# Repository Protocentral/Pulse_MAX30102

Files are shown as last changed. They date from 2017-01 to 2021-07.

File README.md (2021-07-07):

Pulse
================================

[Don't have it yet? Buy one here: Pulse+ Pulse-Ox & Heart Rate Sensor based on MAX30102 (PC-MED-0402)](https://protocentral.com/product/pulse-3-pulse-ox-heart-rate-sensor-based-on-max30102-qwiic-compatible/)
Pulse+ Pulse-Ox & Heart Rate Sensor

This is the new Pulse Plus building on our earlier Pulse board by adding the new MAX30102 chip from Maxim that provides better performance.

The Pulse sensor board from ProtoCentral is our new addition to our open medical hardware line-up. Maxim's MAX30100 is a great new product that combines everything required for a pulse oximeter (including the LEDs and Photodiode !!) on a single tiny chip.

Measuring 14 mm wide and 40 mm long, this board is easily wearable on the finger to measure the pulse of blood. We even provide a Velcro strap to hold it.
Important Note: This device is only meant to be used for Research purposes and is NOT to be used as a medical device. This product is not FDA, CE or FCC approved for consumer use. 

Features:
* Integrates a complete pulse oximeter including the optics. No need for a separate probe. 
* Easy-to-use I2C interface to connect to any host microcontroller
* 880 nm Infrared and 660 nm Red LEDs
* Arduino library available
* Calculates Spo2 values with provided code
* Real-time display of PPG (Photoplethysmogram)

Includes:
----------
* 1x ProtoCentral Pulse Oximeter breakout
* 1x Welgro strap

Repository Contents
-------------------
* **/Software** - Arduino and Processing library and example sketches.
* **/Hardware** - All Eagle design files (.brd, .sch)
* **/extras** -   includes the datasheet

Wiring the Breakout to your Arduino
------------------------------------
Connection with the Arduino board is as follows:
 
|Pulse pin label | Arduino Connection |Pin Function |
|--- |:---:|---:|
| VCC | +5V |  Supply voltage  | 
| SCL | A5 |  Serial clock |
| SDA | A4 |  Serial data |
| GND | |  Gnd |

Using Processing - Data Visualization Software (New!)
-----------------------------------------------------
 Processing is a data visualization software, in existence since 2001, used by artists and scientists alike. It’s an open source coding framework based on Java. If you are familiar with the Arduino environment, the Processing IDE is similar and you won’t have much of a learning curve to climb!
 
 The following are the steps to run the code:

### 1. Download Processing for your operating system

 Download the processing ide latest version from the link

* [MAC] (http://download.processing.org/processing-3.2.1-macosx.zip)
* [Linux 32-bit] (http://download.processing.org/processing-3.2.1-linux32.tgz)
* [Linux 64-bit] (http://download.processing.org/processing-3.2.1-linux64.tgz)
* [Windows 32-bit] (http://download.processing.org/processing-3.2.1-windows32.zip)
* [Windows 64-bit] (http://download.processing.org/processing-3.2.1-windows64.zip)

 Once downloaded, unzip the archive and install the app as per your OS.

### 2. Download the Processing code for Pulse Oximeter visualization

 a. Download the necessary files & directories or clone to your desktop from GitHub.

 b. Unzipping the archive should make a folder by name Pulse that contains the visualization code.

 c. Locate the Processing sketchbook directory on your computer. This should have been created automatically when you installed processing. Depending on your operating system, the path will be as follows:

* On Windows: c:/My Documents/Processing/
* On MAC: /Users/your_user_name/Documents/Processing/
* On Linux: /Home/your_user_name/sketchbook/

**Note:** This directory appears as "Processing" on Windows/Mac, and goes by the name "Sketchbook" on Linux. Create a subdirectory by name "libraries" if one doesn't exist already.

 d. From the above mentioned "Pulse" directory Copy/Move the contents of the Pulse-master/Software/Processing/openview_oximeter folder to the Processing sketchbook directory which is also mentioned above (Locate the Processing sketchbook)

 e. Finally, copy the G4P directories from Pulse-master\Processing\libraries and paste them into the libraries directory of your Processing sketchbook.

 f. You are all set now to get your first PPG wave form and SpO2 reading visualized from the Pulse!

### 3. Open Processing & launch the openview_oximeter

 a. If Processing IDE was open, close it and reopen to refresh the libraries and sketches. The repositories are not refreshed if the IDE was open while the Sketches and Libraries were being updated.

 b. Double-click any of the .pde files in the openview_oximeter directory to open all of the pulse oximeter code in the Processing IDE.

 c. If everything done so far was good, clicking the "run" button on the top left corner of the IDE, should run the code! If it does not, make sure you installed your libraries correctly.

 d. Once the GUI is running, select the port connect with pulse oximeter shield from the "SELECT PORT" dropdown as shown in the figure below

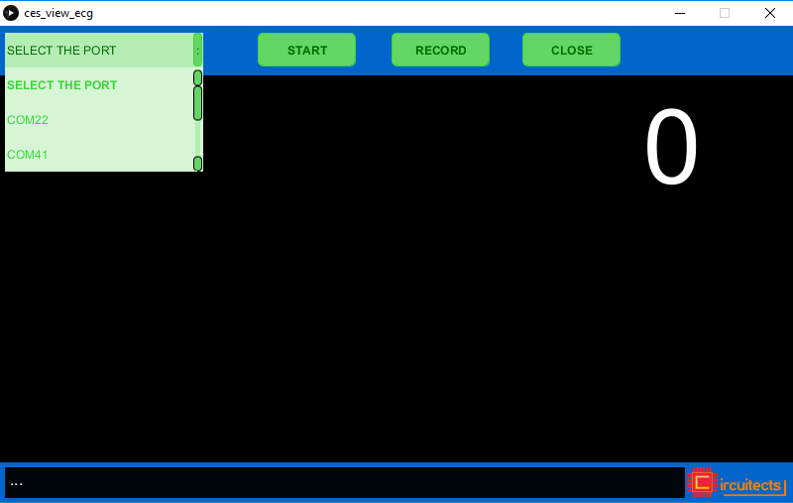
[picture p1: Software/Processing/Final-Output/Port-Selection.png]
Port Selection


 e. Once the port selection is appropriate the START button gets enabled. Click "START" to initiate visualization

 f. You should see the PPG ( RED and IR) waves generated with the values obtained from the Pulse as shown below.

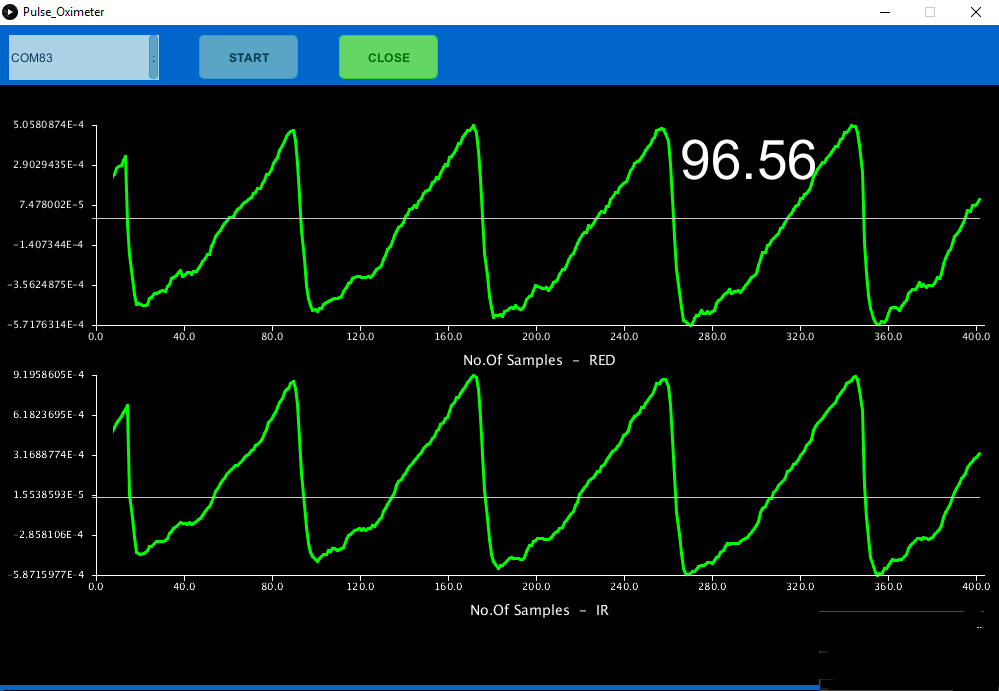
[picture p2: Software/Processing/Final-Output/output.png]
PPG Wave Form in Processing


License Information
===================

This product is open source! Both, our hardware and software are open source and licensed under the following licenses:

Hardware
---------

**All hardware is released under [Creative Commons Share-alike 4.0 International](http://creativecommons.org/licenses/by-sa/4.0/).**


You are free to:

* Share — copy and redistribute the material in any medium or format
* Adapt — remix, transform, and build upon the material for any purpose, even commercially.
The licensor cannot revoke these freedoms as long as you follow the license terms.

Under the following terms:

* Attribution — You must give appropriate credit, provide a link to the license, and indicate if changes were made. You may do so in any reasonable manner, but not in any way that suggests the licensor endorses you or your use.
* ShareAlike — If you remix, transform, or build upon the material, you must distribute your contributions under the same license as the original.

Software
--------

**All software is released under the MIT License(http://opensource.org/licenses/MIT).**

THE SOFTWARE IS PROVIDED "AS IS", WITHOUT WARRANTY OF ANY KIND, EXPRESS OR IMPLIED, INCLUDING BUT NOT LIMITED TO THE WARRANTIES OF MERCHANTABILITY, FITNESS FOR A PARTICULAR PURPOSE AND NONINFRINGEMENT. IN NO EVENT SHALL THE AUTHORS OR COPYRIGHT HOLDERS BE LIABLE FOR ANY CLAIM, DAMAGES OR OTHER LIABILITY, WHETHER IN AN ACTION OF CONTRACT, TORT OR OTHERWISE, ARISING FROM, OUT OF OR IN CONNECTION WITH THE SOFTWARE OR THE USE OR OTHER DEALINGS IN THE SOFTWARE.

Please check [*LICENSE.md*](LICENSE.md) for detailed license descriptions.

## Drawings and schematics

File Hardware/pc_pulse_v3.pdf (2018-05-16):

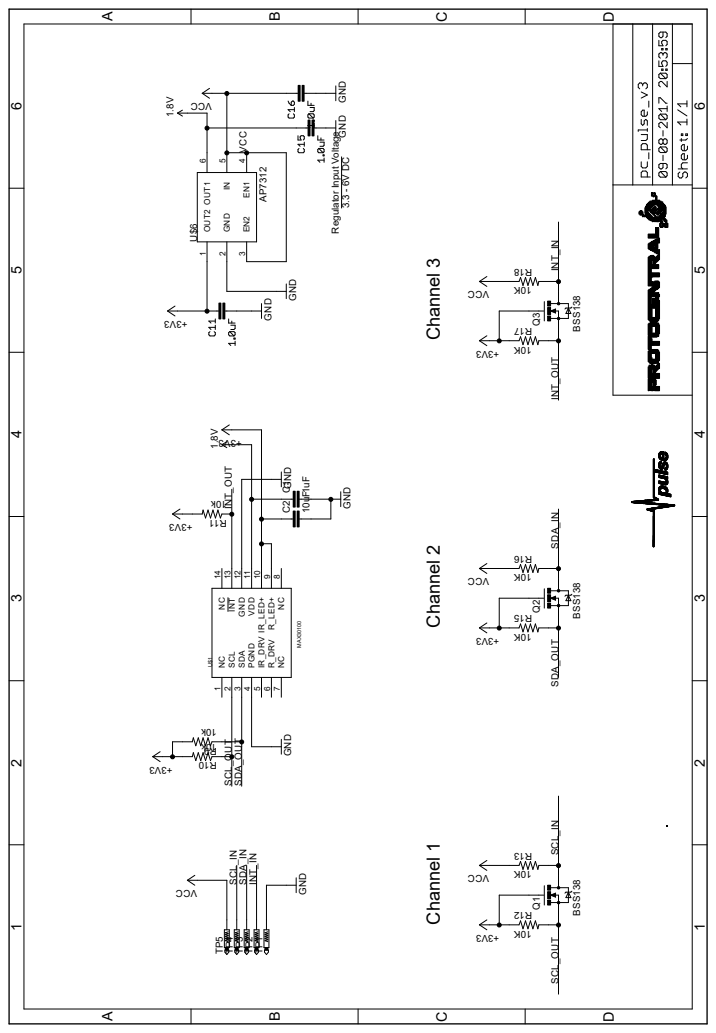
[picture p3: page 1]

R18 TP5 TP4 TP3 TP2 TP1 OUT2 1 GND 2 EN2 3 EN1 4 IN 5 OUT1 6 U$6 SCL_OUT SCL_OUT SDA_OUT SDA_OUT INT_OUT INT_OUT VCC SCL_INSCL_IN SDA_IN SDA_IN INT_IN INT_IN ABCD 1 2 3 4 5 6 ABCD 1 2 3 4 5 6

VCC AP7312 GND GND GND GND 1.8V

VCC Channel 1 Channel 2 Channel 3 NC 1 SCL 2 SDA 3 PGND 4 IR_DRV 5 R_DRV 6 NC 7 NC 8 R_LED+ 9 IR_LED+ 10 VDD 11 GND 12 INT 13 NC 14 U$1 C1 C2

Regulator Input Voltage 3.3 - 6V DC MAX30100 1uF 10uF GNDGND GND GND VCC

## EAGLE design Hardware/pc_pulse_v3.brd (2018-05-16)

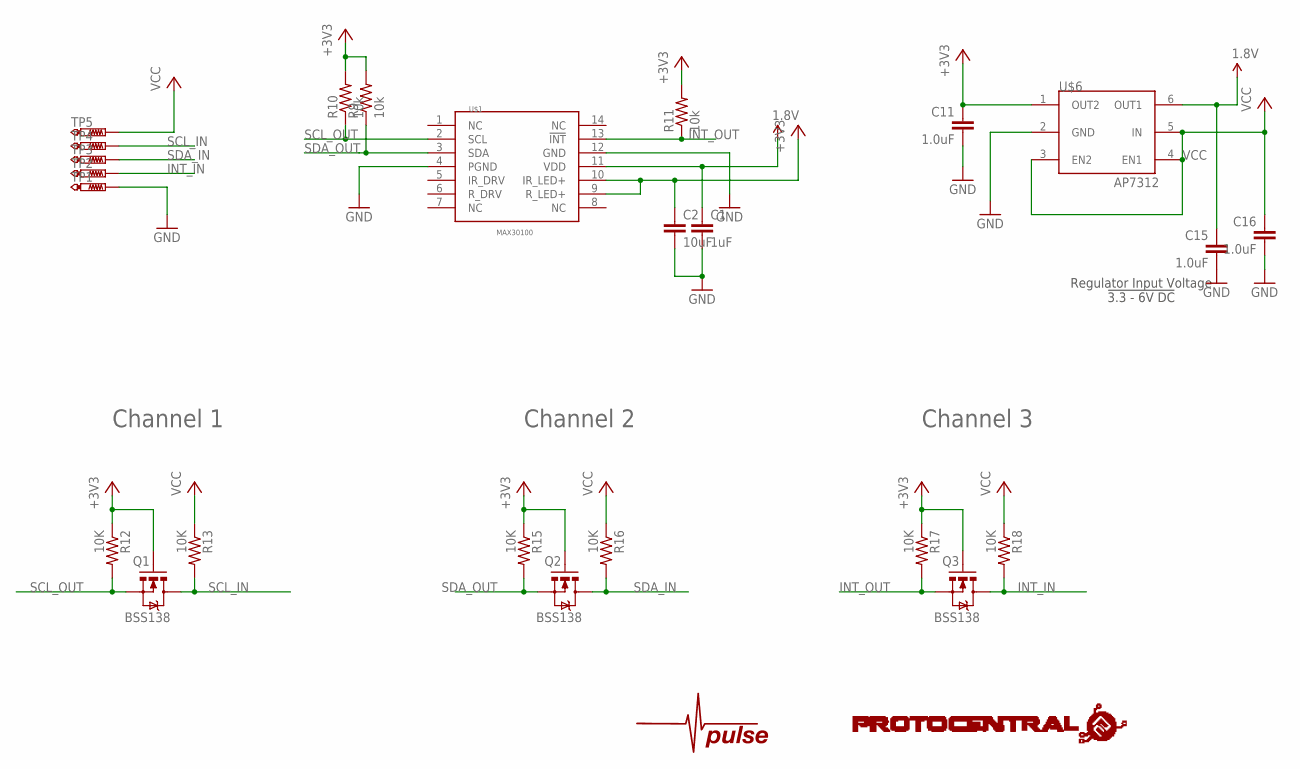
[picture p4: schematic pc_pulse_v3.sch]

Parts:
C1: 1uF; C0805
C2: 10uF; C0805
C11, C15, C16: 1.0uF; 0805
Q1, Q2, Q3: BSS138; SOT23-3
R9, R10, R11: 10k; R0402
R12, R13, R15, R16, R17, R18: 10K; 0402-RES
TP1, TP2, TP3, TP4, TP5: PTR1TP20SQ; TP20SQ
U$1: MAX30100; OESIP-14
U$3: PROTY-LOGO; LOGO-PROTY
U$4: PULSE
U$6: AP7312; SOT26
U$7: PROTY_LOGO_WITH_TEXT; PROTY_WITH_TEXT

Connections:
1.8V: C1.1, C15.1, U$1.11 (VDD), U$6.6 (OUT1)
+3V3: C2.1, C11.1, Q1.1 (G), Q2.1 (G), Q3.1 (G), R9.2, R10.2, R11.2, R12.1, R15.1, R17.1, U$1.9 (R_LED+), U$1.10 (IR_LED+), U$6.1 (OUT2)
GND: C1.2, C2.2, C11.2, C15.2, C16.2, TP1.TP, U$1.4 (PGND), U$1.12 (GND), U$6.2 (GND)
INT_IN: Q3.3 (D), R18.2, TP2.TP
INT_OUT: Q3.2 (S), R11.1, R17.2, U$1.13 (!INT)
SCL_IN: Q1.3 (D), R13.2, TP4.TP
SCL_OUT: Q1.2 (S), R10.1, R12.2, U$1.2 (SCL)
SDA_IN: Q2.3 (D), R16.2, TP3.TP
SDA_OUT: Q2.2 (S), R9.1, R15.2, U$1.3 (SDA)
VCC: C16.1, R13.1, R16.1, R18.1, TP5.TP, U$6.3 (EN2), U$6.4 (EN1), U$6.5 (IN)

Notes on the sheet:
Channel 1
Channel 2
Channel 3
Regulator Input Voltage !3.3 - 6V DC!

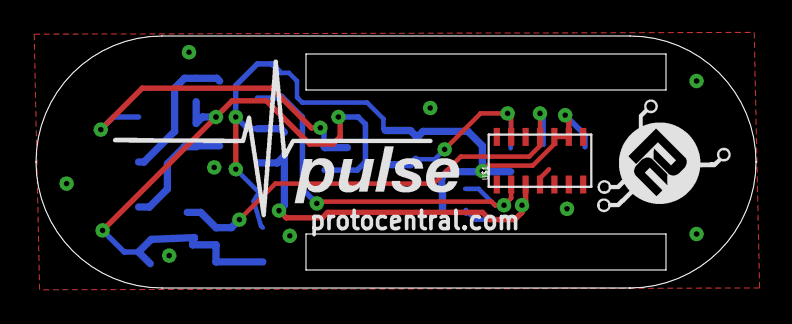
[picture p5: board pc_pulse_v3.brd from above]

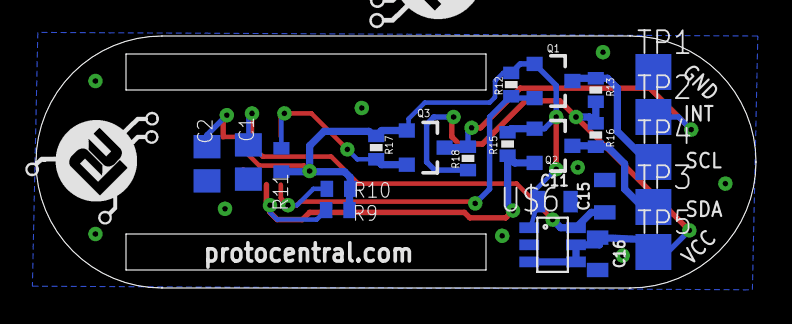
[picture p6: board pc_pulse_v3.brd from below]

Board: 4 copper layers, 40.0 x 14.0 mm, 28 parts (25 on the bottom side), 10 nets.

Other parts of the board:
U$5: PROTY-LOGO; LOGO-PROTY

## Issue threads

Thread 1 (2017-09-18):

error in the Max30102

omsrivathsa, 2017-09-18:
i have been trying to execute Max30102 break out board   from protocentral  is heck of mess !!! unable to decode the break out

VenkateshBhat, 2017-09-18:
@omsrivathsa
Sorry for the inconvenience caused, could you please attach the error message you are getting.

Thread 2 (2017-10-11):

issue with reading of data

SayedBaqer, 2017-10-11:
hi,
thanks for your hard work on this library,
i have GY-max30102 i try your library and sketch,
but output is not possible to understand only squares!
i need to use it for test pulse of human then if it work i need to use it for egg pulse monitor if you can help

VenkateshBhat, 2017-10-11:
@SayedBaqer thanks for your kind words!,
Could you please share the output graph?

SayedBaqer, 2017-10-11:
I display by Serial monitors,
If there is any way to get only the pulse rate in Pulse per minute will be great, and later if we can adjust it to be able to ready egg embryo pulse

On Oct 11, 2017, at 16:44, Venkatesh Bhat <notifications@github.com<mailto:notifications@github.com>> wrote:

@SayedBaqer<https://github.com/sayedbaqer> thanks for your kind words!,
Could you please share the output graph?

—
You are receiving this because you were mentioned.
Reply to this email directly, view it on GitHub<https://github.com/Protocentral/Pulse_MAX30102/issues/2#issuecomment-335814151>, or mute the thread<https://github.com/notifications/unsubscribe-auth/ANY6VbJGcDfN7lsfdS_mlQS57SZz0mRKks5srMYogaJpZM4P1dnP>.

VenkateshBhat, 2017-10-12:
The sample code we provided plots the reflected RED and IR light. Sparkfun has a library for SpO2 calculation check here -https://github.com/sparkfun/SparkFun_MAX3010x_Sensor_Library

SayedBaqer, 2017-10-12:
Dose not work well on GY-MAX-30102

Best regards,
Sayed Baqer Mohammed Alseba

On Oct 12, 2017, at 08:19, Venkatesh Bhat <notifications@github.com<mailto:notifications@github.com>> wrote:

The sample code we provided plots the reflected RED and IR light. Sparkfun has a library for SpO2 calculation check here -https://github.com/sparkfun/SparkFun_MAX3010x_Sensor_Library

—
You are receiving this because you were mentioned.
Reply to this email directly, view it on GitHub<https://github.com/Protocentral/Pulse_MAX30102/issues/2#issuecomment-336023526>, or mute the thread<https://github.com/notifications/unsubscribe-auth/ANY6VVGlEi-QGHIxDxBJnG1JDvYfiWV5ks5sraFngaJpZM4P1dnP>.

VenkateshBhat, 2017-10-12:
Without proper housing external light interference may cause the improper readings.

ashwinsundarka, 2018-07-24:
The example codes are given for MAX30105 and they are using MAX20105.h but I have 30102 from protocentral, I am not able to code it. Any help you can do?

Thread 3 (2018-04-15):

Files upload confusion??

dvogel3, 2018-04-15:
Hello,

I'm trying to upload the Continuos file to an Arduino Uno Bluno Nano v1.4 board. In the Arduino IDE, I compiled and uploaded the Continuos file and when I attempt to run the code, the Max30102 is not lighting up and is outputting a flat green line and 0, as to indicate something is wrong. I followed your steps thoroughly from pulling your code, but I'm confused as to what to upload to make the Bluno Nano work. Can you make any suggestions?

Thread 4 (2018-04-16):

Error with noise and graph output

lholtslander, 2018-04-16:
Hello,

I cloned your code and followed the instructions thoroughly. I am using the PULSE+ PULSE-OX & HEART RATE SENSOR BASED ON MAX30102 from Protocentral and followed the link directly from the manufacturer page. I can see the red light on the Protocentral board on and working, and I am using an Arduino RedBoard. However, the output of my graph is not clear like in the instruction manuals and is not giving me any signal. Attached is an image of the graph output.

Any advice?

Thank you!

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

xeacott, 2019-02-26:
Hi, I am trying to also use the Processing library and I'm not getting any information even to the Processing IDE. Can you explain what you have running on the Arduino and how it interacts with the Processing IDE?

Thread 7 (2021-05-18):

Problem with ESP8266

amansinghaljpr, 2021-05-18:
It does not work properly with the esp8266 and when i open the serial monitor i cannot see any data on the screen for the sensor

joicetm, 2021-05-18:
What is the board you are using?Please share the part number.
Have you crosschecked the uart rx/tx pins ?
Are you using arduino serial terminal ?
Have you tried it on an arduino board ?

amansinghaljpr, 2021-05-18:
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

I am using the esp8266 feather huzzah with the MAX30102 sensor . And yes i have checked the connections and everything but the board gets into reset mode when i try to check the oxygen . Heart rate and normal readings all work just fine

kondababu931, 2022-01-30:
can any one helpme iam unable add protocentralmax30102 header file . library

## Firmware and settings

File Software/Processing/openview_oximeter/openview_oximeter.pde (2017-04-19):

// Need G4P library
import processing.serial.*;
import g4p_controls.*;
import java.awt.*;
import javax.swing.JFileChooser;

import java.math.*;
import java.io.FileWriter;
import java.io.BufferedWriter;
import java.util.Date;
import static javax.swing.JOptionPane.*;

import java.io.FileReader;
import java.io.BufferedReader;
import java.text.DateFormat;
import java.text.SimpleDateFormat;

//import signal.library.*;

/************** Packet Validation  **********************/
private static final int CESState_Init = 0;
private static final int CESState_SOF1_Found = 1;
private static final int CESState_SOF2_Found = 2;
private static final int CESState_PktLen_Found = 3;

private static final int CESState_EOF_Wait = 98;
private static final int CESState_EOF_Found = 99;

/*CES CMD IF Packet Format*/
private static final int CES_CMDIF_PKT_START_1 = 0x0A;
private static final int CES_CMDIF_PKT_START_2 = 0xFA;
private static final int CES_CMDIF_PKT_STOP = 0x0B;

/*CES CMD IF Packet Indices*/
private static final int CES_CMDIF_IND_START_1 = 0;
private static final int CES_CMDIF_IND_START_2 = 1;
private static final int CES_CMDIF_IND_LEN = 2;
private static final int CES_CMDIF_IND_LEN_MSB = 3;
private static final int CES_CMDIF_IND_PKTTYPE = 4;
private static final int CES_CMDIF_IND_DATA0 = 5;
private static final int CES_CMDIF_IND_DATA1 = 6;
private static final int CES_CMDIF_IND_DATA2 = 7;

/* CES OTA Data Packet Positions */
private static int CES_OTA_DATA_PKT_POS_LENGTH = 0;
private static int CES_OTA_DATA_PKT_POS_CMD_CAT = 1;
private static int CES_OTA_DATA_PKT_POS_DATA_TYPE = 2;
private static int CES_OTA_DATA_PKT_POS_SENS_TYPE = 3;
private static int CES_OTA_DATA_PKT_POS_RSVD = 4;
private static int CES_OTA_DATA_PKT_POS_SENS_ID = 5;
private static int CES_OTA_DATA_PKT_POS_DATA = 6;

private static int CES_OTA_DATA_PKT_OVERHEAD = 6;
private static int CES_CMDIF_PKT_OVERHEAD = 5;

/************** Packet Related Variables **********************/

int ecs_rx_state = 0;
int CES_Pkt_Len;
int CES_Pkt_Pos_Counter, CES_Pkt_Data_Counter1, CES_Pkt_Data_Counter2;
int CES_Pkt_PktType;
char DataRcvPacket1[] = new char[500];
char DataRcvPacket2[] = new char[500];

/************** ControlP5 Related Variables **********************/

int colorValue;
HelpWidget helpWidget;
HeaderButton headerButton;
MessageBox msgBox;
SPO2_cal s;
boolean visibility=false;

/************** Graph Related Variables **********************/

double maxAxis_ir, minAxis_ir, maxAxis_red, minAxis_red;
double receivedVoltage_RED, receivedVoltage_IR;
BigDecimal min, max;

/************** File Related Variables **********************/

boolean logging = false;
FileWriter output;
JFileChooser jFileChooser;
Date date;
FileReader readOutput;
String line;
BufferedWriter bufferedWriter;
DateFormat dateFormat;

/************** Port Related Variables **********************/

Serial port = null;
int Ss = -1;
String[] comList;
boolean serialSet;
boolean portSelected = false;
String portName;
char inString = '\0';
String selectedPort;

/************** Logo Related Variables **********************/

PImage logo;

/************** General Variables **********************/

boolean startPlot, Serialevent = false;
String msgs;
int startTime = 0;

int pSize = 400;
float[] xdata = new float[pSize];
float[] ydata = new float[pSize];
float[] AvgYdata = new float[pSize];
float[] zdata = new float[pSize];
float[] AvgZdata = new float[pSize];
int arrayIndex = 1;
Graph g, g1;
float time =0;
BigDecimal avg, rms, a;
double additionFactor_red, additionFactor_ir;
float value1, value2;
float RedAC = 0, RedDC = 0, IrAC = 0, IrDC = 0;
//SignalFilter myFilter;

public void setup() {
  size(1000, 700, JAVA2D);
  //fullScreen();
  createGUI();
  customGUI();
  // Place your setup code here

  date = new Date();
  logo = loadImage("logo.png");

  headerButton = new HeaderButton(0, 0, width, 60);
  helpWidget = new HelpWidget(0, height - 30, width, 40); 
  msgBox = new MessageBox();
  s = new SPO2_cal();
  g = new Graph(100, 100, width-120, 200);
  g1 = new Graph(100, 350, width-120, 200);
  setChartSettings();
  for (int i=0; i<pSize; i++) 
  {
    time = time + 2;
    xdata[i]=time;
    ydata[i] = 0;
    zdata[i] = 0;
  }
  time = 0;
  g.GraphColor = color(0, 255, 0);
  g.Title = "RED";
  g1.GraphColor = color( 0, 255, 0);
  g1.Title = "IR";
 // myFilter = new SignalFilter(this);
}

/*********************************************** Draw Function *********************************************************/

public void draw() {
  background(0);
  while (portSelected == true && serialSet == false)
  {
    startSerial(comList);
  }
  background(0);
  if (startPlot)
  {
    g.LineGraph(xdata, ydata);
    g1.LineGraph(xdata, zdata);
  }

  g.DrawAxis();
  g1.DrawAxis();

 // msgBox.MessageBoxAxis(0, height - 100, width, 70);
 // msgBox.draw();
  headerButton.draw();
  helpWidget.draw();
}

/*********************************************** Opening Port Function ******************************************* **************/

void startSerial(String[] theport)
{
  try
  {
    port = new Serial(this, selectedPort, 57600);
    port.clear();
    serialSet = true;
    msgs = "Port "+selectedPort+" is opened Click Start button";
    portName = "\\"+selectedPort+".txt";
  }
  catch(Exception e)
  {
    msgs = "Port "+selectedPort+" is busy";
    showMessageDialog(null, "Port is busy", "Alert", ERROR_MESSAGE);
    System.exit (0);
  }
}

/*********************************************** Serial Port Event Function *********************************************************/

void serialEvent (Serial blePort) 
{
  Serialevent = true;
  inString = blePort.readChar();
  ecsProcessData(inString);
}

/*********************************************** Getting Packet Data Function *********************************************************/
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

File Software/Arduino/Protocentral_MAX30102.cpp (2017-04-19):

#include "Arduino.h"
#include <Wire.h>
#include "Protocentral_MAX30102.h"

MAX30100::MAX30100(){

}

void MAX30100::setLEDs(pulseWidth pw, ledCurrent red, ledCurrent ir){
  uint8_t reg = I2CreadByte(MAX30100_ADDRESS, MAX30100_SPO2_CONFIG);
  reg = reg & 0xFC; // Set LED_PW to 00
  I2CwriteByte(MAX30100_ADDRESS, MAX30100_SPO2_CONFIG, reg | pw);     // Mask LED_PW
 // I2CwriteByte(MAX30100_ADDRESS, MAX30100_LED_CONFIG, (red<<4) | ir); // write LED configs
}

void MAX30100::setSPO2(sampleRate sr){
  uint8_t reg = I2CreadByte(MAX30100_ADDRESS, MAX30100_SPO2_CONFIG);
  reg = reg & 0xE3; // Set SPO2_SR to 000
  I2CwriteByte(MAX30100_ADDRESS, MAX30100_SPO2_CONFIG, reg | (sr<<2)); // Mask SPO2_SR
  reg = I2CreadByte(MAX30100_ADDRESS, MAX30100_MODE_CONFIG);
  reg = reg & 0xf8; // Set Mode to 000
  I2CwriteByte(MAX30100_ADDRESS, MAX30100_SPO2_CONFIG, reg | 0x03); // Mask MODE
}

int MAX30100::getNumSamp(void){
    uint8_t wrPtr = I2CreadByte(MAX30100_ADDRESS, MAX30100_FIFO_WR_PTR);
    uint8_t rdPtr = I2CreadByte(MAX30100_ADDRESS, MAX30100_FIFO_RD_PTR);
    return (abs( 16 + wrPtr - rdPtr ) % 16);
}

void MAX30100::readSensor(void){
  uint8_t temp[6] = {0};  // Temporary buffer for read values
  I2CreadBytes(MAX30100_ADDRESS, MAX30100_FIFO_DATA, &temp[0], 6);  // Read four times from the FIFO
  //temp[0] = 0x11; temp[1] = 0x22; temp[2] = 0x33; temp[4] = 0x44; temp[5] = 0x55;temp[6] = 0x66;
  IR =  (long)((long)((long)temp[0]&0x03)<<16) | (long)temp[1]<<8 | (long)temp[2];    // Combine values to get the actual number
  RED = (long)((long)((long)temp[3] & 0x03)<<16) |(long)temp[4]<<8 | (long)temp[5];   // Combine values to get the actual number
}

void MAX30100::shutdown(void){
  uint8_t reg = I2CreadByte(MAX30100_ADDRESS, MAX30100_MODE_CONFIG);  // Get the current register
  I2CwriteByte(MAX30100_ADDRESS, MAX30100_MODE_CONFIG, reg | 0x80);   
}

void MAX30100::reset(void){
  uint8_t reg = I2CreadByte(MAX30100_ADDRESS, MAX30100_MODE_CONFIG);  // Get the current register
  I2CwriteByte(MAX30100_ADDRESS, MAX30100_MODE_CONFIG, reg | 0x40);   // mask the RESET bit
}

void MAX30100::startup(void){
  uint8_t reg = I2CreadByte(MAX30100_ADDRESS, MAX30100_MODE_CONFIG);  // Get the current register
  I2CwriteByte(MAX30100_ADDRESS, MAX30100_MODE_CONFIG, reg & 0x7F);   // mask the SHDN bit
}

int MAX30100::getRevID(void){
  return I2CreadByte(MAX30100_ADDRESS, MAX30100_REV_ID);
}

int MAX30100::getPartID(void){
  return I2CreadByte(MAX30100_ADDRESS, MAX30100_PART_ID);
}

void MAX30100::begin(pulseWidth pw, ledCurrent ir, sampleRate sr){

  I2CwriteByte(MAX30100_ADDRESS, MAX30100_INT_ENABLE1, 0xc0); 
  I2CwriteByte(MAX30100_ADDRESS, MAX30100_INT_ENABLE2, 0x00); 
  I2CwriteByte(MAX30100_ADDRESS, MAX30100_FIFO_WR_PTR, 0x00); 
  I2CwriteByte(MAX30100_ADDRESS, MAX30100_OVRFLOW_CTR, 0x00); 
  I2CwriteByte(MAX30100_ADDRESS, MAX30100_FIFO_RD_PTR, 0x00); 
  I2CwriteByte(MAX30100_ADDRESS, MAX30100_FIFO_CONFIG, 0x00); 
  I2CwriteByte(MAX30100_ADDRESS, MAX30100_MODE_CONFIG, 0x03); 
  I2CwriteByte(MAX30100_ADDRESS, MAX30100_SPO2_CONFIG, 0x07); 
  I2CwriteByte(MAX30100_ADDRESS, MAX30100_LED1_AMP , 0x24); 
  I2CwriteByte(MAX30100_ADDRESS, MAX30100_LED2_AMP, 0x24); 
//  I2CwriteByte(MAX30100_ADDRESS, MAX30100_PILOT, 0x7f); 
  
}

void MAX30100::printRegisters(void){
  Serial.println(I2CreadByte(MAX30100_ADDRESS, MAX30100_INT_STATUS1),  BIN);
  Serial.println(I2CreadByte(MAX30100_ADDRESS, MAX30100_INT_STATUS2),  BIN);
  Serial.println(I2CreadByte(MAX30100_ADDRESS, MAX30100_FIFO_WR_PTR), BIN);
  Serial.println(I2CreadByte(MAX30100_ADDRESS, MAX30100_INT_ENABLE1), BIN);
  Serial.println(I2CreadByte(MAX30100_ADDRESS, MAX30100_OVRFLOW_CTR), BIN);
  Serial.println(I2CreadByte(MAX30100_ADDRESS, MAX30100_FIFO_RD_PTR),   BIN);
  Serial.println(I2CreadByte(MAX30100_ADDRESS, MAX30100_FIFO_DATA), BIN);
  Serial.println(I2CreadByte(MAX30100_ADDRESS, MAX30100_FIFO_CONFIG), BIN);
 // Serial.println(I2CreadByte(MAX30100_ADDRESS, MAX30100_LED_CONFIG),  BIN);
  Serial.println(I2CreadByte(MAX30100_ADDRESS, MAX30100_MODE_CONFIG),   BIN);
  Serial.println(I2CreadByte(MAX30100_ADDRESS, MAX30100_SPO2_CONFIG),   BIN);
  Serial.println(I2CreadByte(MAX30100_ADDRESS, MAX30100_LED1_AMP),      BIN);
  Serial.println(I2CreadByte(MAX30100_ADDRESS, MAX30100_LED2_AMP),     BIN);
  Serial.println(I2CreadByte(MAX30100_ADDRESS, MAX30100_PILOT ),     BIN);
  Serial.println(I2CreadByte(MAX30100_ADDRESS, MAX310100_MLED_CTRL1),     BIN);
  Serial.println(I2CreadByte(MAX30100_ADDRESS, MAX310100_MLED_CTRL2),     BIN);
  Serial.println(I2CreadByte(MAX30100_ADDRESS, MAX30100_TEMP_INTG),     BIN);
  Serial.println(I2CreadByte(MAX30100_ADDRESS,  MAX30100_TEMP_FRAC),     BIN);
  Serial.println(I2CreadByte(MAX30100_ADDRESS,MAX30100_DIE_TEMP),     BIN);
  Serial.println(I2CreadByte(MAX30100_ADDRESS, MAX30100_PROX_INT_TRESH),     BIN);
  Serial.println(I2CreadByte(MAX30100_ADDRESS, MAX30100_REV_ID),     BIN);
  Serial.println(I2CreadByte(MAX30100_ADDRESS, MAX30100_PART_ID),     BIN);
}

// Wire.h read and write protocols
void MAX30100::I2CwriteByte(uint8_t address, uint8_t subAddress, uint8_t data)
{
	Wire.beginTransmission(address);  // Initialize the Tx buffer
	Wire.write(subAddress);           // Put slave register address in Tx buffer
	Wire.write(data);                 // Put data in Tx buffer
	Wire.endTransmission();           // Send the Tx buffer
}

uint8_t MAX30100::I2CreadByte(uint8_t address, uint8_t subAddress)
{
	uint8_t data; // `data` will store the register data
	Wire.beginTransmission(address);         
	Wire.write(subAddress);	                 
	Wire.endTransmission(false);             
	Wire.requestFrom(address, (uint8_t) 1);  
	data = Wire.read();                      
	return data;                             
}

void MAX30100::I2CreadBytes(uint8_t address, uint8_t subAddress, uint8_t * dest, uint8_t count)
{
	Wire.beginTransmission(address);   // Initialize the Tx buffer
	// Next send the register to be read. OR with 0x80 to indicate multi-read.
	Wire.write(subAddress);     
	Wire.endTransmission(false);
	uint8_t i = 0;
	Wire.requestFrom(address, count);  // Read bytes from slave register address
	while (Wire.available())
	{
		dest[i++] = Wire.read(); 
	}
}

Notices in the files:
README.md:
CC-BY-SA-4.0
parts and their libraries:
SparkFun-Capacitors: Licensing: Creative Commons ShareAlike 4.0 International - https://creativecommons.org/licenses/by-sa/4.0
